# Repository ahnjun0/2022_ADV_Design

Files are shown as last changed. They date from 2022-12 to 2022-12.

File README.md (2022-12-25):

# 목을 펴자! 거북목 예방 및 자세교정 서비스

2022학년도 2학기 어드벤처디자인 과목(아두이노) 팀프로젝트 협업을 위한 repo입니다.

- 프로젝트 기간 : 2022.11.09 - 2022.12.26 (48일간)

## 팀 소개

- 팀원 : 김민욱(202255521), 안준영(202255567), 장건호(202255597)
- 팀명 : 정컴침팬지(2조)
- 대표메일 : ahnjun0@pusan.ac.kr (안준영)

---

## Code

    ahnjun0/2022_ADV_Design
    ├ Document
    │   ├ Plan
    │   │   ├ 기자재신청목록_02조_정컴침팬지(11.18).xlsx
    │   │   └ 프로젝트 설계 발표자료 초안_02조_정컴침팬지(11.18).pptx
    │   │
    │   ├ 3DPrinter_stl // Case 3DPrinter 제작용
    │   │   ├ Body.stl
    │   │   └ Cover.stl
    │   │
    │   └ Presentation
    │       └ 프로젝트 결과 발표자료_02조_정컴침팬지.pptx
    │
    ├ Main
    │   ├ Main_Sketch
    │   │   ├ Main_Sketch.ino // 착용하게 될 Main Arduino에 컴파일하는 Sketch file
    │   │   └ pitches.h
    │   │
    │   ├ Sub_Sketch
    │   │   └ Sub_Sketch.ino // 초음파 센서를 연결하게 될 Sub Arduino에 컴파일하는 Sketch file
    │   │
    │   ├ I2C_Scanner
    │   │   └ I2C_Scanner.ino // I2C Address 확인용
    │   │
    │   ├ library
    │   │   └ Arduino-LiquidCrystal-I2C-library-master.zip // I2C LCD 사용 위한 Library
    │   │    [https://github.com/fdebrabander/Arduino-LiquidCrystal-I2C-library]
    │   │
    │   ├ Regression
    │   │   ├ main.py
    │   │   ├ measurement.csv // 측정한 각도-저항값 데이터
    │   │   └ LinearRegression.png
    │   │
    │   └ Testbed // 각종 테스트용
    │       └ Testbed.ino
    │
    └ README.md

## 기타 공지사항

- 함수 작성 시 Doxygen(@brief, @details, @param, @return 등)을 이용하여 설명합시다.
- 변수 이름은 간결하게, snake_case를 이용합시다.
- 업로드 이전, 본인 기기에서 컴파일 해서 오류가 없는지 확인하는 미덕을 갖춥시다.

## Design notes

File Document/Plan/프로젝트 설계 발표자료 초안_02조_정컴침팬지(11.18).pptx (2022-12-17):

## 거북목 예방 및 자세 교정 서비스 프로젝트 설계 발표자료(초안)

2022년 2학기 어드벤처디자인(002) 프로젝트
Team 2. 정컴침팬지 발표자료
(김민욱, 안준영, 장건호)

Adventure Design

## 배경 및 필요성

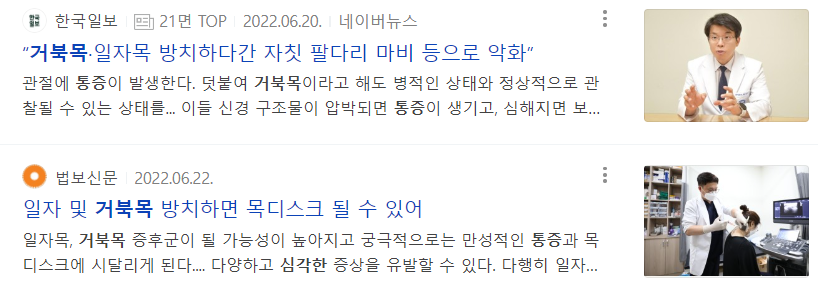
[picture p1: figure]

거북목 증후군의 가장 큰 원인은 눈높이보다 낮은 컴퓨터 모니터를 장시간 같은 자세로 내려다보는 것

거북목 증후군 환자는 매년 증가하고 있다!

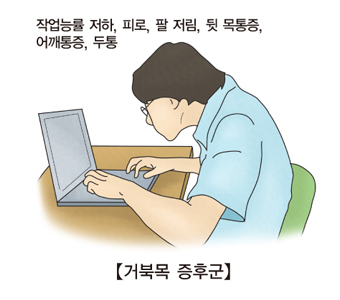
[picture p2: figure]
거북목을하고 노트북으로 작업을 하는 남성 및 거북목증후군의증상 작업능률저하,피로,팔저림,뒷목통증,어깨통증,두통

- 서울아산병원

## 기존 시스템이나 서비스의 현상 및 한계

”

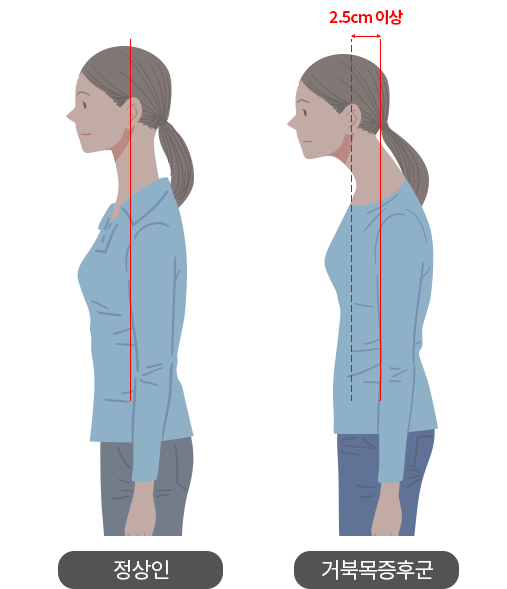
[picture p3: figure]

컴퓨터 모니터 등을 내려다볼 때,
무의식중에 시간이 흐를수록 머리를
앞으로 숙이는 자세를 하게 된다.
이 때문에 아래쪽 목뼈는 과하게 구부러지고, 위쪽 목뼈와 머리뼈는 머리를 젖히는 방향으로 배열된다. (출처 : 헬스조선)

거북목 자세는 무의식 중에 하게 되지만, 누군가 지적해주지 않는다면 내가 거북목 자세를 하고 있는 중인지 스스로 판단할 수 없는 문제가 생긴다.

## 제안하는 시스템의 목표와 특성

- 거북목 상태 측정 모듈 & 측정값에 따른 일상 속 자세 교정 제안 시스템

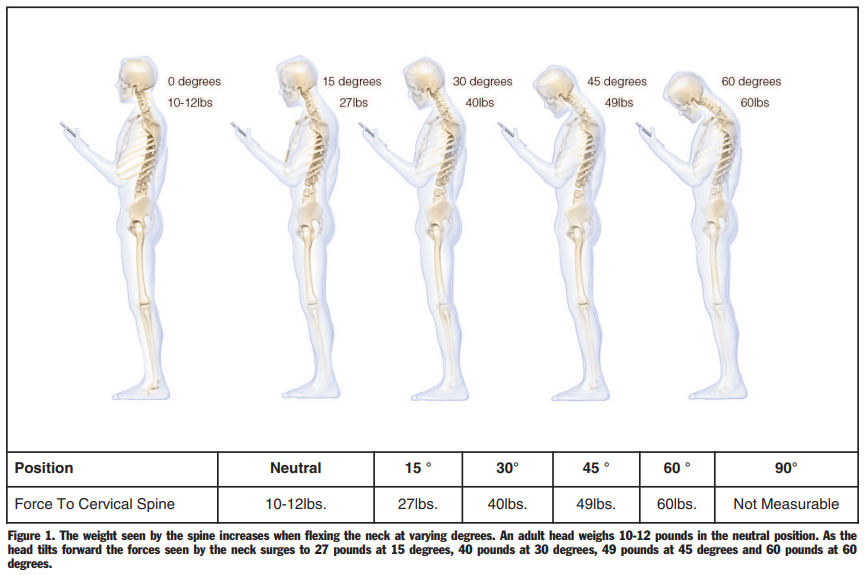
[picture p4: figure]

- 거북목 상태임을 인지하기 위해 두 가지 요소를 시스템에서 사용
• 구부림(flex) 센서 이용한
경추의 각도 측정
• 초음파(ultrasonic) 센서
이용한 모니터와의 거리 측정

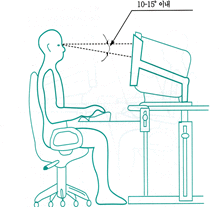
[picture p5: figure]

- 두 센서의 데이터를 종합 평가하여, 피험자가 거북목 상태인지 주기적 판단
- 거북목 상태라면, 부저와 어플리케이션으로 피험자에게 거북목 상태임을 인지시킴
- 거북목 상태를 해소할 수 있는 바른 자세 유도

## 제안하는 시스템의 내용 및 방법

16x2 Text LCD

Arduino
Mega2560

블루투스 모듈

▼ 사용자 신체에 부착

부저

구부림
센서

블루투스 모듈

Bluetooth

Bluetooth

▼ 모니터에 부착

안드로이드
어플리케이션

블루투스 모듈

Arduino
Mega2560

초음파
센서

## 제안하는 시스템의 내용 및 방법

아두이노 Mega2560 x 2

- 여러가지 센서 제어
- 안드로이드와 BT 통신
- 두 아두이노간 BT 통신

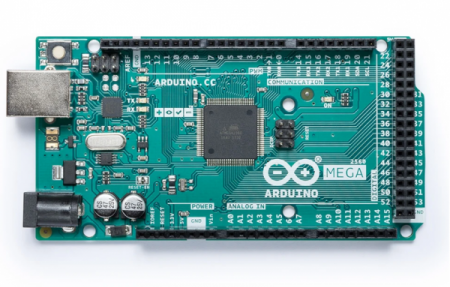
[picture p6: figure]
디바이스마트,오픈소스/코딩교육 > 아두이노 > 정품보드/쉴드/키트,Arduino,Arduino Mega 2560 (R3),A000067 / 이탈리아 정품 / ATmega2560 기반, 디지털 I/O 54핀 및 아날로그 입력 16핀 / 256KB 메모리 / 동작 전압 : 5V

블루투스 모듈

- 두 아두이노 사이의
통신과, 모바일 기기와의 통신을 위한 모듈

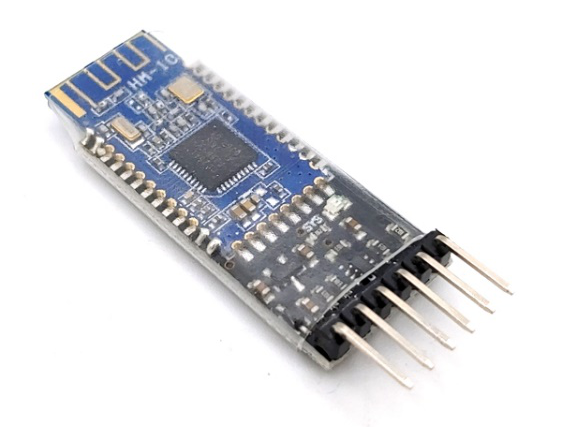
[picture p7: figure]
디바이스마트,MCU보드/전자키트 > 통신/네트워크 > 블루투스/BLE,SZH,HM-10 블루투스 4.0 BLE 모듈 [SZH-EK108],2.5V ~ 3.3V / 최대 50mA 필요 / 블루투스 4.0 기반(BLE) / 직렬 UART 인터페이스

초음파(Ultrasonic) 센서

- 사용자와 모니터 사이 거리 측정

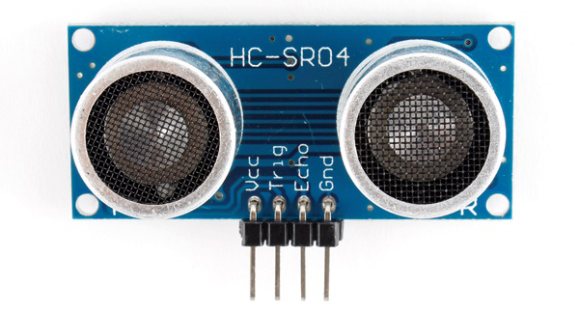
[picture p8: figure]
디바이스마트,MCU보드/전자키트 > 센서모듈 > 라이다/거리/초음파/라인 > 초음파,SZH,HC-SR04P 3.3V/5V 호환 초음파 거리센서 모듈 [SZH-USBC-004],초음파를 사용하여 거리를 측정할 수 있는 제품 / 기존 HC-SR04 대비 작동 전압의 폭이 넓어진(3V ~ 5V) 버전 / 측정거리 : 2cm ~ 450cm(5V),400cm(3.3V) / 측정 각도 : 15도 이하
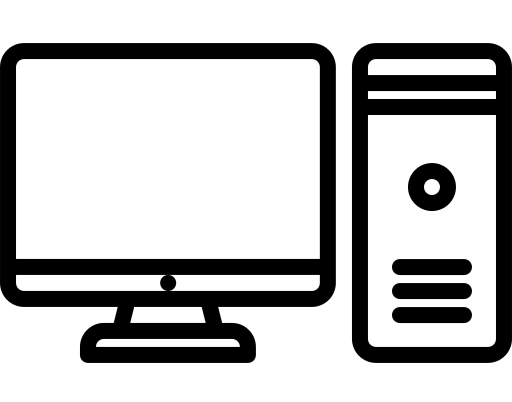
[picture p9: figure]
컴퓨터 무료 아이콘
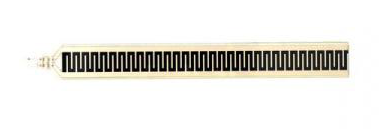
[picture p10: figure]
디바이스마트,센서 > 압력/힘(Force)센서 > 휨(Flex)센서,SZH,플렉스 압력 센서 130mm [SZH-SEN02],구부림 감지 플렉스 압력 센서 / 타입 : 일반형 (직사각형) / 길이 : 130mm / 너비 : 15mm / 최대 하중 : 10KG / 회로도 및 예제소스 제공

구부림(Flex) 센서

- 사용자 경추의 각도 측정

16x2 LCD with IIC

- 경추의 초기 각도 입력, 현재 경추의 각도를 보여주는 기능 제공

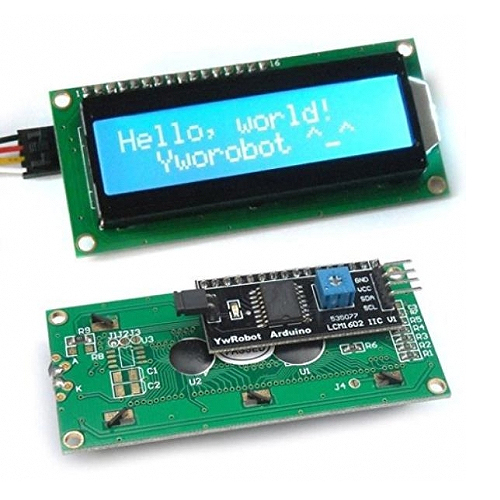
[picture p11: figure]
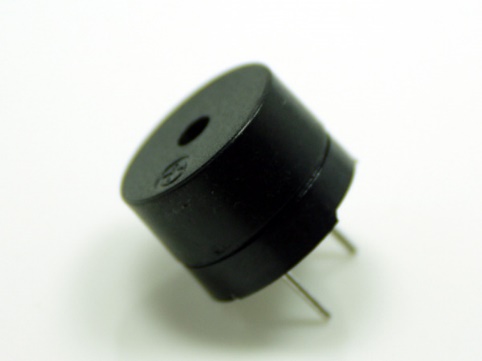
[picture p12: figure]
디바이스마트,스위치/부저/전기부품 > 부저/스피커/사이렌 > 부저 > 세라믹 부저,㈜일오삼이엘씨,IMT12D2001AP,세라믹 부저 /HC12G-P series (원래 제품명) 피에조 부조 / PIEZO(DIP) / 30mA / 2048Hz / 85dB / 12mm(D)x8.5mm(H) / 수동소저 제품입니다.

피에조 부저

- 일정 각도 이상으로
경추가 회전하면, 부저로 사용자에게 경고 전달

PC

- 구부림 센서의 리턴값을, 실제 경추의 각도와 비교하여 회귀분석을 실시

## 제안하는 시스템의 내용 및 방법

FSR 구부림 센서
(저항값 return)

경추의 각도 측정
with 각도기

PC에 저장

+

반복 실행

회귀분석을 통해
각도와 저항값 간회귀식 도출

도출된 회귀식

시스템 내
코드에 저장

거북목 여부
판단 시 사용

## 제안하는 시스템의 내용 및 방법

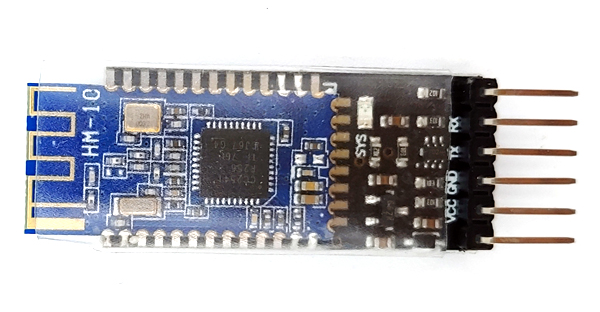
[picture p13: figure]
디바이스마트,MCU보드/전자키트 > 통신/네트워크 > 블루투스/BLE,SZH,HM-10 블루투스 4.0 BLE 모듈 [SZH-EK108],2.5V ~ 3.3V / 최대 50mA 필요 / 블루투스 4.0 기반(BLE) / 직렬 UART 인터페이스

슬레이브(Slave) 모드
- 초음파 센서가 연결된 아두이노 보드에 연결, 데이터 전송

· 블루투스 모듈 사용 관련

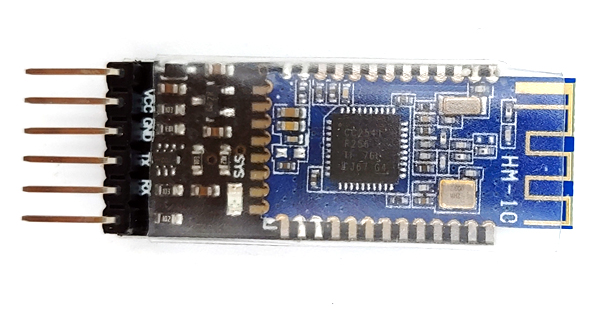
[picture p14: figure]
디바이스마트,MCU보드/전자키트 > 통신/네트워크 > 블루투스/BLE,SZH,HM-10 블루투스 4.0 BLE 모듈 [SZH-EK108],2.5V ~ 3.3V / 최대 50mA 필요 / 블루투스 4.0 기반(BLE) / 직렬 UART 인터페이스

마스터(Master) 모드
- 휨 센서가 연결된 아두이노 보드에 연결, BT 연결을 총괄제어

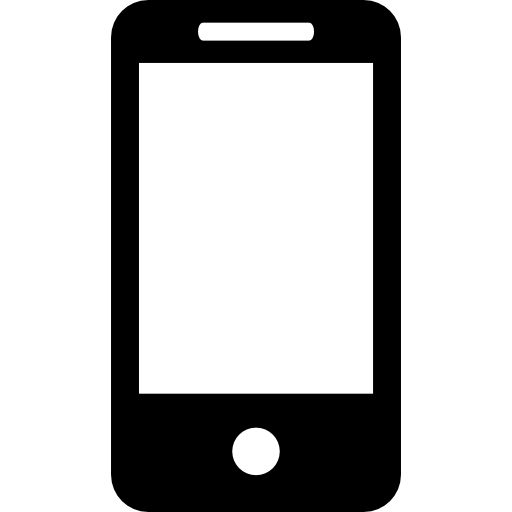
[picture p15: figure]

- 블루투스 통해
제작된 안드로이드
어플리케이션으로 데이터 전송.

## 제안하는 시스템의 내용 및 방법

· I²C 16x2 TEXT LCD 사용 관련

기존에 사용하던 16x2 LCD
→ 최소 6개(4bit) 이상의 신호선 연결 필요,
아두이노의 가용 핀 현격히 감소.

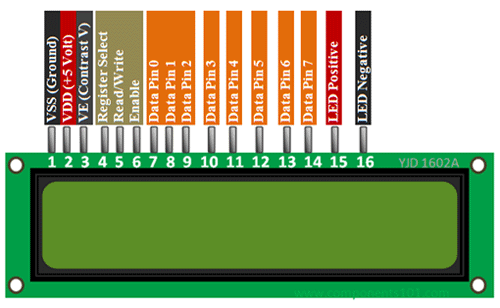
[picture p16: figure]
16x2 LCD Display Module Pinout, Features, Description & Datasheet
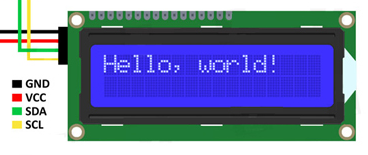
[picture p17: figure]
디바이스마트,오픈소스/코딩교육 > 아두이노 > LED/LCD모듈,SZH,아두이노 I2C 1602 LCD 모듈 [SZH-EK101],아두이노 호환 16 * 2 캐릭터(문자) LCD 모듈 / Blue 백라이트 + White 문자 / I2C 모듈이 있어 아두이노와 손쉽게 연결할 수 있습니다 / 80 * 36mm

I²C 모듈이 장착된 16x2 LCD
→ I²C 방식을 사용함으로써, 신호선 2개만으로 LCD에 텍스트 표시 가능, 회로의 복잡성 감소.

## 활용 방안 및 향후 발전 방향

- 자세 교정이 필요한 사용자에게 스스로 거북목 상태임을 판단하여 올바른 자세를 지도할 수 있음
- 모터 등을 추가하여 바른 자세가 되도록 제어하고, 안마기와 결합하여 일정 시간 이상 거북목 상태였다면 안마기를 작동하며, 정도가 심각한 경우 주위의 정형외과 등으로 안내하는 등의 기능이 추가된 시스템으로 발전할 수 있음.

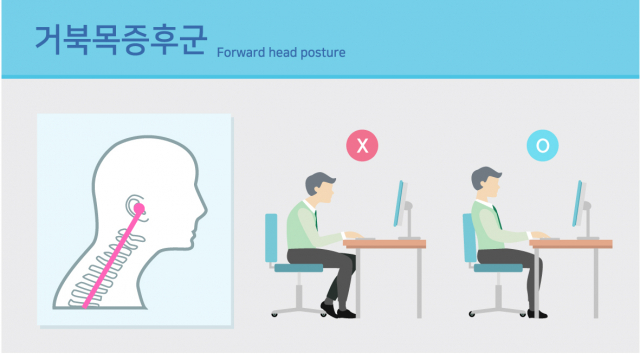
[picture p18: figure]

## 필요한 부품 목록

- 블루투스 직렬포트 모듈 HC-06 (DIP) [SZH-EK010] https:// (https://www.devicemart.co.kr/goods/view?no=1278220)www.devicemart.co.kr/goods/view?no=1278220
- 구부림센서 휨센서 Flex Sensor (4.5인치) https:// (https://mechasolution.com/shop/goods/goods_view.php?goodsno=24)mechasolution.com/shop/goods/goods_view.php?goodsno=24
- 구부림센서 / 휨센서 / Flex Sensor (2.2인치) https:// (https://mechasolution.com/shop/goods/goods_view.php?goodsno=203)mechasolution.com/shop/goods/goods_view.php?goodsno=203
- 아두이노 I2C 1602 LCD 모듈 [SZH-EK101] https (https://www.devicemart.co.kr/goods/view?no=1327456):// (https://www.devicemart.co.kr/goods/view?no=1327456)www.devicemart.co.kr/goods/view?no=1327456
- PCB보드 스냅보드 편리한 사이즈변형 만능기판- 97x90mm 블랙https (https://www.devicemart.co.kr/goods/view?no=12506665):// (https://www.devicemart.co.kr/goods/view?no=12506665)www.devicemart.co.kr/goods/view?no=12506665
- 3색 점퍼용 단선- 0.6 파이 [1미터단위] https:// (https://www.devicemart.co.kr/goods/view?no=1153807)www.devicemart.co.kr/goods/view?no=1153807
- 수축튜브 2파이/검정(1M) https:// (https://www.devicemart.co.kr/goods/view?no=12772)www.devicemart.co.kr/goods/view?no=12772
- 아두이노 PS2 조이스틱 모듈 [SZH-EK056] https:// (https://www.devicemart.co.kr/goods/view?no=1287087)www.devicemart.co.kr/goods/view?no=1287087
- 핀헤더소켓 Single 1x5 Straight(2.54mm) https:// (https://www.devicemart.co.kr/goods/view?no=12494)www.devicemart.co.kr/goods/view?no=12494
- 핀헤더 Single 1x4Pin Straight(2.54mm) https:// (https://www.devicemart.co.kr/goods/view?no=1312958)www.devicemart.co.kr/goods/view?no=1312958
- 반원분도기(18cm 반원) https:// (https://www.devicemart.co.kr/goods/view?no=12818468)www.devicemart.co.kr/goods/view?no=12818468
- 실습용 무연납(HGF-1.0-50) https:// (https://www.devicemart.co.kr/goods/view?no=1272735)www.devicemart.co.kr/goods/view?no=1272735
- 메이커봇 PLA 정품 필라멘트 0.2kg 1.75mm [화이트] https (https://www.devicemart.co.kr/goods/view?no=13915146):// (https://www.devicemart.co.kr/goods/view?no=13915146)www.devicemart.co.kr/goods/view?no=13915146

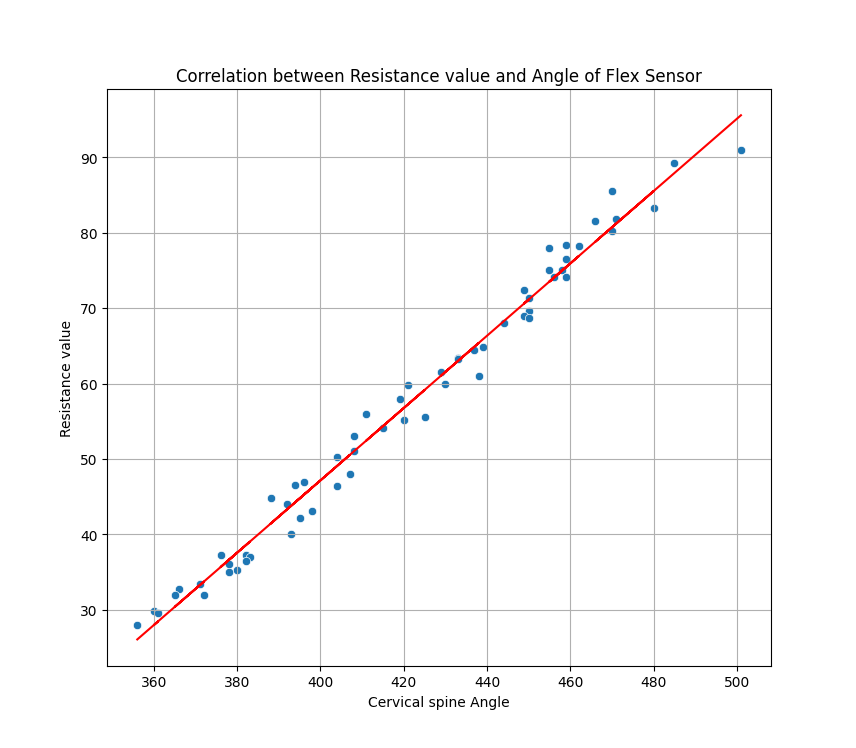
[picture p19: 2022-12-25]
Main/Regression/LinearRegression.png

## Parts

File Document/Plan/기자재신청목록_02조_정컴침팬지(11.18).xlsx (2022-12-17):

번호 | 상품코드 | 품목 | 상품명(옵션명) | 제조사 | 링크 | 수량 | 단가 | 합계금액
1 | 1278220 | 블루투스 모듈 | 블루투스 직렬포트 모듈 HC-06 (DIP) [SZH-EK010] | OEM | https://www.devicemart.co.kr/goods/view?no=1278220 | 2 | 7150 | 14300
2 | 3106 | 구부림센서 | 구부림센서 휨센서 Flex Sensor (4.5인치) | Sparkfun | https://mechasolution.com/shop/goods/goods_view.php?goodsno=24 | 1 | 35000 | 35000
3 | 7582 | 구부림센서 | 구부림센서 / 휨센서 / Flex Sensor (2.2인치) | Adafruit | https://mechasolution.com/shop/goods/goods_view.php?goodsno=203 | 1 | 15500 | 15500
4 | 1327456 | I2C LCD | 아두이노 I2C 1602 LCD 모듈 [SZH-EK101] | SMG | https://www.devicemart.co.kr/goods/view?no=1327456 | 1 | 3960 | 3960
5 | 12506665 | 만능기판 | PCB보드 스냅보드 편리한 사이즈변형 만능기판- 97x90mm 블랙 | 일렉트로쿠키 | https://www.devicemart.co.kr/goods/view?no=12506665 | 1 | 3300 | 3300
6 | 1153807 | 점퍼용 전선 | 3색 점퍼용 단선- 0.6 파이 [1미터단위] | 동우전선 | https://www.devicemart.co.kr/goods/view?no=1153807 | 2 | 440 | 880
7 | 12772 | 열수축튜브 | 수축튜브 2파이/검정(1M) | ㈜한국에이스통신 | https://www.devicemart.co.kr/goods/view?no=12772 | 1 | 154 | 154
8 | 1287087 | 조이스틱 모듈 | 아두이노 PS2 조이스틱 모듈 [SZH-EK056] | SMG-A | https://www.devicemart.co.kr/goods/view?no=1287087 | 1 | 1980 | 1980
9 | 12494 | 핀헤더소켓 | 핀헤더소켓 Single 1x5 Straight(2.54mm) | CONNFLY | https://www.devicemart.co.kr/goods/view?no=12494 | 3 | 99 | 297
10 | 1312958 | 핀헤더 | 핀헤더 Single 1x4Pin Straight(2.54mm) | GIN LING | https://www.devicemart.co.kr/goods/view?no=1312958 | 10 | 33 | 330
11 | 12818468 | 각도기 | 반원분도기(18cm 반원) | 아톰 | https://www.devicemart.co.kr/goods/view?no=12818468 | 1 | 2486 | 2486
12 | 1272735 | 땜납 | 실습용 무연납(HGF-1.0-50) | 거상인 | https://www.devicemart.co.kr/goods/view?no=1272735 | 1 | 7700 | 7700
13 | 13915146 | 필라멘트 | 메이커봇 PLA 정품 필라멘트 0.2kg 1.75mm [화이트] | MakerBot | https://www.devicemart.co.kr/goods/view?no=13915146 | 1 | 44000 | 44000
14 |  |  |  |  |  |  |  | 0

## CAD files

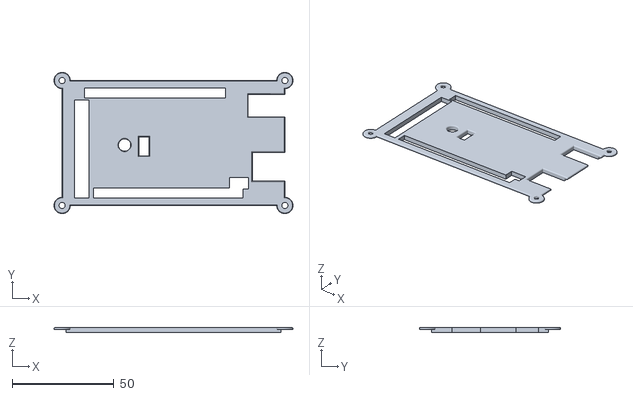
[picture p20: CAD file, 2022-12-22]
Document/3DPrinter_stl/Cover.stl
117.3 x 69.3 x 2.50

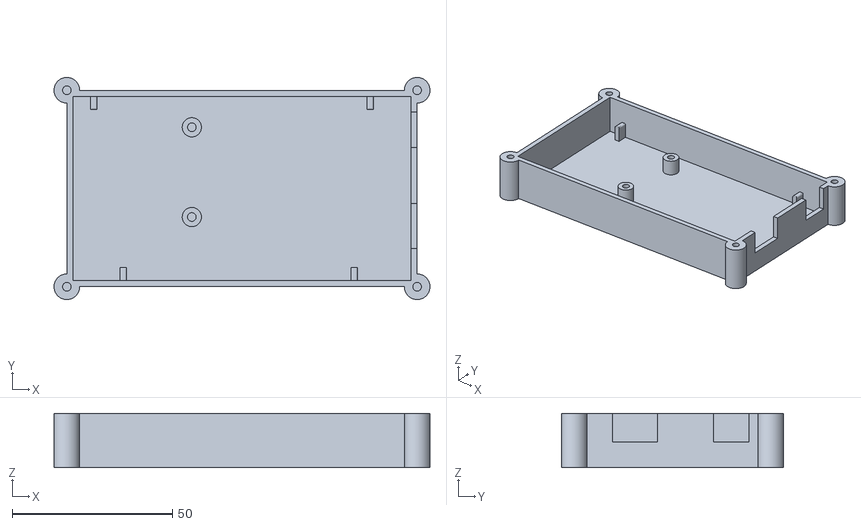
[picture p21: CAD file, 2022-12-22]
Document/3DPrinter_stl/Body.stl
117.3 x 69.3 x 17.0

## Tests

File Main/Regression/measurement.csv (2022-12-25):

Cervical spine Angle | Resistance value
91 | 501
89.3 | 485
85.6 | 470
83.3 | 480
81.8 | 471
81.5 | 466
80.2 | 470
78.4 | 459
78.2 | 462
78 | 455
76.5 | 459
75.1 | 458
75 | 455
74.1 | 456
74.1 | 459
72.4 | 449
71.3 | 450
69.6 | 450
69 | 449
68.7 | 450
68 | 444
64.9 | 439
64.5 | 437
63.4 | 433
63.2 | 433
61.5 | 429
61 | 438
60 | 430
59.8 | 421
58 | 419
56 | 411
55.5 | 425
55.2 | 420
54.1 | 415
53 | 408
51 | 408
50.2 | 404
48 | 407
46.9 | 396
46.6 | 394
46.4 | 404
44.8 | 388
44 | 392
43.1 | 398
42.1 | 395
40 | 393
37.3 | 376
37.3 | 382
37 | 383
36.5 | 382
36 | 378
35.2 | 380
35 | 378
33.4 | 371
32.7 | 366
32 | 365
32 | 372
29.8 | 360
29.6 | 361
28 | 356

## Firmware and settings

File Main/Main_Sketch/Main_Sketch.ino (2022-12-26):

// #include <Wire.h> Included in LiquidCrystal_I2C.h
#include <LiquidCrystal_I2C.h>
#include <pitches.h>

LiquidCrystal_I2C lcd(0x27, 16, 2);

/* Global Variable */

double angle_initial = 0; // 구부림 센서에서 처음 return되는 값. if 기준치 이상, ERROR.
int dis_initial = 0;//초음파 센서에서 처음 return되는 값. if 기준치 이하, ERROR.
int flex_pin = A4; // 구부림센서 핀 번호
int buzzer_pin = A8; // 부저(스피커) 핀 번호
int joystick_VRX_pin = A0; // 조이스틱 VRX 핀 번호
int joystick_VRY_pin = A1; // 조이스틱 VRY 핀 번호
int joystick_SW_pin = 13; // 조이스틱 SW 핀 번호



/* Reference Value */

double on_turtle_angle = 50; // 거북목 상태인 각도 기준값, 상수 값.
double on_turtle_distance = 30; // 거북목 상태인 거리 기준값, 상수 값



/* Temp Value */



/* Function Definition */

double resist_to_angle(void);
int distance(void);
void buzzer(int length, int time);
void i2c_lcd(String text, int k);
void tx_message(char* message);
int joystick(void);



void setup() {
    Serial.begin(9600);
    Serial1.begin(9600); // 초음파센서에서 Data Rx
    Serial2.begin(9600); // 스마트폰으로 Data Tx
    
    lcd.begin(); //LCD 초기화
    lcd.backlight(); //백라이트 on

    pinMode(joystick_SW_pin, INPUT_PULLUP);//z축 버튼  

    lcd.clear();
    i2c_lcd("  Press Button  ", 0);
}



void loop() {

/*
 * 들어온 값을 if로 비교해서
 * 만약 그 값이 거북목 기준값보다 크다면
 * 1. buzzer() 함수를 이용해서 buzzer를 울리고
 * 2. i2c_lcd() 함수를 이용해서 lcd에 출력하고
 * 3. tx_message() 함수를 이용해서 휴대폰으로 보낸다.
*/

    if ( joystick() == 5 ) {
        dis_initial = distance();
        if (dis_initial > 100) dis_initial = 100; //모니터에서 인간까지 거리 상한값.
        lcd.clear();
        i2c_lcd(" Init Success!! ", 0);
        i2c_lcd("Distance : "+String(dis_initial)+"cm", 1);        
    }

    if (dis_initial != 0) {
        double angle = resist_to_angle();
        int now_dis = distance();
        if (dis_initial > 100) dis_initial = 100;
        
        if ((angle < on_turtle_angle) && (dis_initial - now_dis > on_turtle_distance)) {
<<<<<<< HEAD
            char* message = "Warning!! Stretch your neck plz!\nWatch this video.\nhttps://www.youtube.com/watch?v=TWGXLs5a8Ig\n\n";
=======
            char* message = "Warning!! Stretch your neck plz!\nWhatch this video.\nhttps://www.youtube.com/watch?v=TWGXLs5a8Ig\n\n";
>>>>>>> a9cd904bb981c7213f2394007eaf2ee89be5abc7
            tx_message(message);
            lcd.clear();
            i2c_lcd("   Warning!!!   ",0);
            i2c_lcd("Angle : "+String(angle)+"deg", 1);
            buzzer(100, 3);
        }
    }
}



/**
 * @brief 저항값을 각도로 만들기 위한 함수.
 * @details 함수 내에서 휨센서로 저항값을 입력받고, 미리 계산된 선형회귀 식에 따라 각도 값을 return한다.
 * @param void
 * @return double 값의 각도를 return한다.
 */
double resist_to_angle(void) {
    double resist = analogRead(flex_pin); // 구부림 센서의 return value
    double angle = 0.4795 * resist - 144.6579; // 선형회귀로 식 구하기
    return angle;
}



/**
 * @brief 거북목 상태일 때 작동시킬 Buzzer(Speaker).
 * @param length 작동시킬 길이. ms 단위.
 * @param time 작동시킬 횟수. (ex. 삑 삑 삑 삑)
 */
void buzzer(int length, int time) {
    for (int k = 0; k < time; k++) {
       tone(buzzer_pin, NOTE_C6, length);
    }
}



/**
 * @brief text로 들어온 파일을 16*2 LCD에 출력하도록 하는 함수입니다.
 * @details 입력은 16자 전부와, 줄 번호가 들어옵니다. (0번 줄, 1번 줄)
 *           https://popcorn16.tistory.com/206 참고하시면 좋습니다.
 * @param text pointer 방식으로 char* 문자열이 들어옵니다
 * @param k int 방식으로 줄 번호를 알려줍니다. (k = 0일때 16x2에서 0번째 줄)
 */
void i2c_lcd(String text, int k) {
    lcd.setCursor(0, k);
    lcd.print(text);
}


/**
 * @brief 조이스틱의 방향에 따라, 출력값을 결정.
 * @details 조이스틱의 동작 원리는 https://blog.naver.com/boilmint7/220927175653
 *           해당 링크 속의 블로그를 참고하시면 편할겁니다.
 *           핀 번호는 상단에 적혀있는 joystick_NNN_value 변수를 사용해주세요
 * @param void
 * @return int 
 */
int joystick(void){
    int joy_x = analogRead(joystick_VRX_pin);
    int joy_y = analogRead(joystick_VRY_pin);
    bool joy_z = digitalRead(joystick_SW_pin);
    int control = 0;
  
    if (joy_x < 100) control = 3;
    if (joy_x > 100) control = 4;
    if (joy_y < 100) control = 1;
    if (joy_y > 100) control = 2;
    if (joy_z == LOW) control = 5; // Using INPUT_PULLUP

    delay(100);

    return control;
}



/**
 * @brief 모니터와 이용자의 거리를 전송받는 함수입니다.
 * @details
 * @param void
 * @return int
 */
int distance(void){
    if (Serial1.available()) {
        int dis;
        String string = Serial1.readStringUntil('\n');
        Serial.println(string);
        dis = string.toInt();
        if (dis > 0) return dis;

     } 
}



/**
 * @brief 휴대폰으로 메시지를 전송하는 함수입니다.
 * @details 현재 각도와 영상 링크 등이 담긴 텍스트 메시지를
 *                   BLuetooth Terminal HC-05 APP으로 전송
 * @param message 
 */
void tx_message(char* message) {
    Serial2.println(message);
}

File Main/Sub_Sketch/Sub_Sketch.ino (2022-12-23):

/* Global Variable */

int trigpin = 2; // 초음파 센서 trigPin
int echopin = 3; // 초음파 센서 echoPin

/* Reference Value */


/* Function Definition */


void setup() {
    // put your setup code here, to run once:
    Serial.begin(9600);
    Serial1.begin(9600);
    pinMode(trigpin, OUTPUT);
    pinMode(echopin, INPUT);  
}

void loop() {
    // put your main code here, to run repeatedly:
    digitalWrite(trigpin, HIGH);
    delay(10);
    digitalWrite(trigpin, LOW);
    float duration = pulseIn(echopin, HIGH);
    float distance = duration * 340 / 10000 / 2;
    int dis_int = (int)distance;
    String dis_str = String(dis_int);
    delay(50);
    Serial1.println(dis_str);
    Serial.println(dis_str);
}

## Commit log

2022-12-17 (최초 제출 초안 파일들)
    [기자재신청목록_02조_정컴침팬지(11.18).xlsx]
2022-12-20 221220 Main_Sketch 기본설정
2022-12-20 main.py 패키지 import
2022-12-20 Main_Sketch 수정
2022-12-20 함수 일부 추가
2022-12-20 Main Sketch 일부수정 및 요청사항 추가 (221221/12:50)
    [Main_Sketch.ino]
2022-12-20 Main Sketch 일부수정 및 요청사항 추가 (221221/12:51)
    [Main_Sketch.ino]
2022-12-20 Sub_Sketch, I2C Scanner, README 수정 (221221/03:31)
    [I2C_Scanner.ino, Main_Sketch.ino, Sub_Sketch.ino]
2022-12-20 Sub_Sketch, I2C Scanner, README 수정 (221221/03:41)
    [Sub_Sketch.ino]
2022-12-20 Sub_Sketch, I2C Scanner, README 수정 (221221/04:02)
    [Main_Sketch.ino]
2022-12-20 Sub_Sketch, I2C Scanner, README 수정 (221221/04:03)
    [Main_Sketch.ino]
2022-12-20 Main_Sketch 수정 (221221/04:15)
2022-12-20 Sub_Sketch, I2C Scanner, README 수정 (221221/04:17)
    [Main_Sketch.ino]
2022-12-20 Main_Sketch 수정 (221221/05:03)
2022-12-22 Case for Arduino Mega2560 (Thingiverse revised) (221222, 16:51)
    [Body.stl, Cover.stl, Extra.stl]
2022-12-23 3DPrinter stl 관련 수정(221223, 11:54)
    [Extra.stl]
2022-12-23 Main_Sketch 수정사항(221223, 12:00)
    [Extra.stl]
2022-12-23 23일 최종 커밋 (1223, 2314)
2022-12-24 Main_Sketch 일부편집(15:16)
2022-12-24 일부수정
2022-12-24 Revert "Update Main_Sketch.ino"
    This reverts commit dbaecabfe8b0c55a44fb93310c295939fe53e8a6.
    [Main_Sketch.ino]
2022-12-24 각종 수정 (1225, 02:47)
    [Main_Sketch.ino, Testbed.ino]
2022-12-24 가제 변경
2022-12-25 최종 (221226, 05:31)
    [measurement.csv]
2022-12-25 상대위치 반영
2022-12-26 최종최종 (1226, 12:22)
2022-12-26 진짜최종_배포직전Push
